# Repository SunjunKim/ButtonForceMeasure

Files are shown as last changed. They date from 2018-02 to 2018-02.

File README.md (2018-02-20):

# Button pressing force measurement device
# Last update: Feb 19, 2018
# Author: Sunjun Kim (kuaa.net@gmail.com)

Works with FSS 1500 sensor & 626 Bearing

# Parts needed
* M4 x (12--25 mm) * 3 ea (+ 3 M4 nuts)
* M6 x (15--25 mm) Flat head * 2ea
* M6 Tap (for making thread on DivingBoard part)
* 3D printed parts (See https://cad.onshape.com/documents/8884241d92b3924385b88df5/w/f3e7b9c0423dc323fdf4269c/e/ec01502cc8bd3c084f737220 for the latest version)

# Assembly
 - TBA

# Firmware
 - Upload FSS1500 to an Arduino ATMega328p (e.g., UNO) or ATMega32U4 (e.g., Leonardo) based board.
 - Serial baud rate: 115200
 - You can check the serial values from Arduino Serial monitor
 - You can log the values through the logSerial.sh bash script
  USAGE: ./logSerial.sh [PORT] [BAUD] [OUTPUT FILE]
  e.g., ./logSerial.sh /dev/tty.usbmodem1421 115200 log.csv

# Visualizer
 - Coded in Processing (tested with ver. 3.3.6, Check http://processing.org/)
 - It connects to the last serial port listed in the system (works with the most setup)
 - It first find the idle value (counting stabilized signal within <2 deviation)
 - After detecting a button press (other than idle value), it visualizes it with a graph (with some lead time before and after the button press).

 # Accelerometer
 - Accelerometer (Spartkfun ADXL335 breakout board) added to A2(X-axis), A3(Y-axis), A4(Z-axis)
 - Cx, Cy, Cz filtering capacitors --> set to 0.01uF (=500Hz bandwidth)
 - Fingertip mount ()

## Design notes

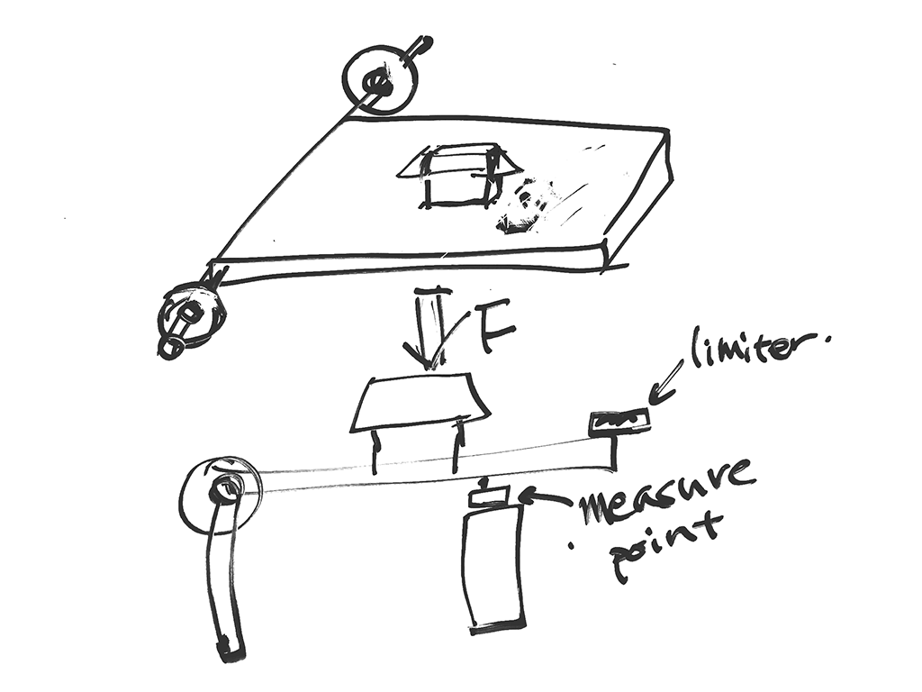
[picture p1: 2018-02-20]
Measuring_apparatus_concept.png

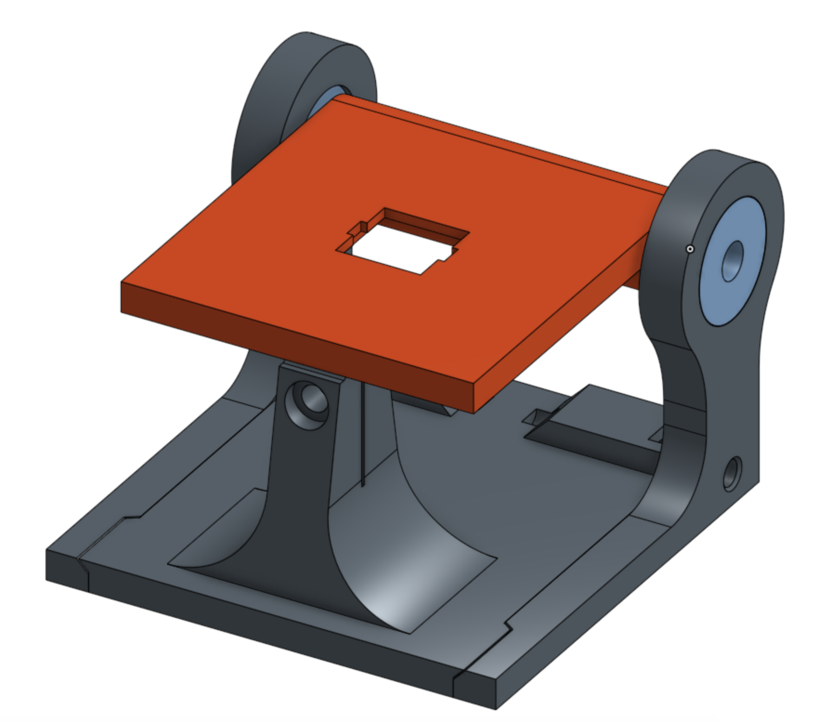
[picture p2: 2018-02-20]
Overview.png

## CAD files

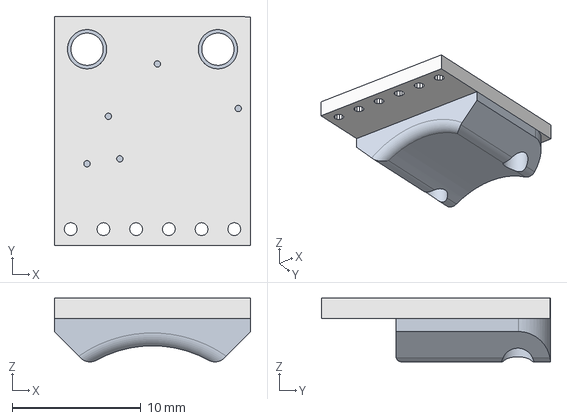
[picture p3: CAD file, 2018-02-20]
models/Fingertip_ADXL335_attachment/Fingertip_Attachment_assembly.step
15.2 x 17.8 x 4.96 mm
ADXL335_Breakout001

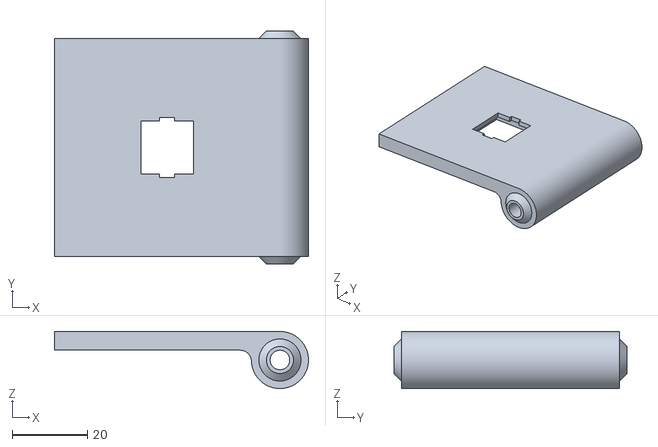
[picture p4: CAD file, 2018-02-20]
DivingBoard.stl
67.6 x 62.0 x 15.2

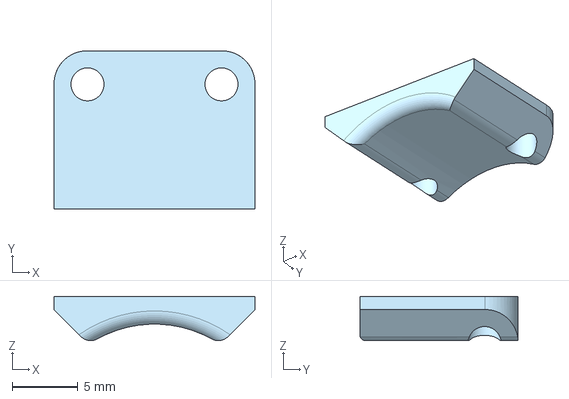
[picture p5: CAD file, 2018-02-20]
models/Fingertip_ADXL335_attachment/Fingertip_Attachment.step
15.2 x 12.0 x 3.36 mm

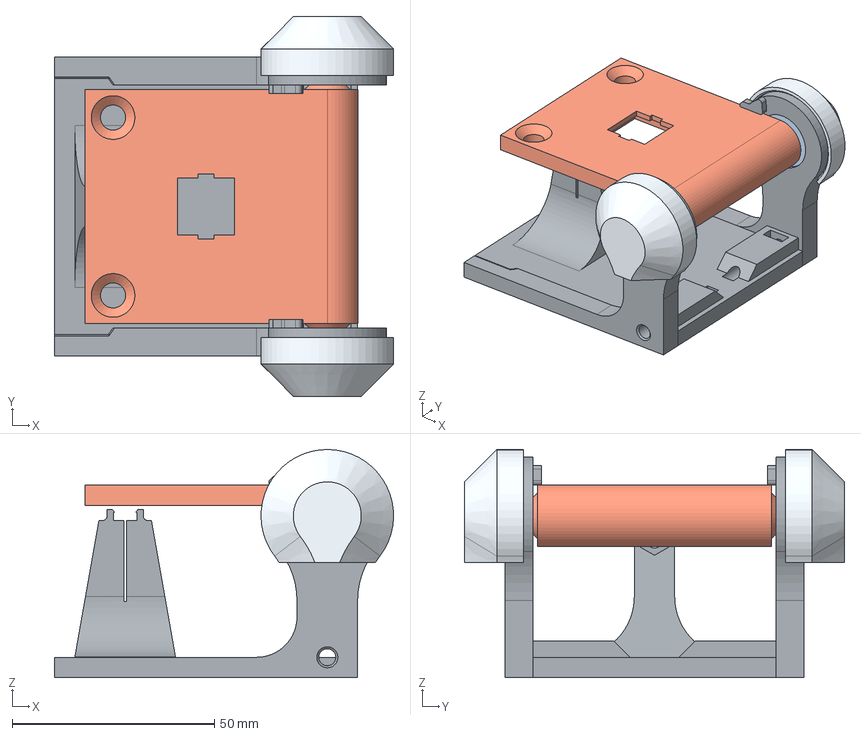
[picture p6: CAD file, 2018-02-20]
models/Mounting Base/Base.step
83.9 x 94.0 x 56.4 mm

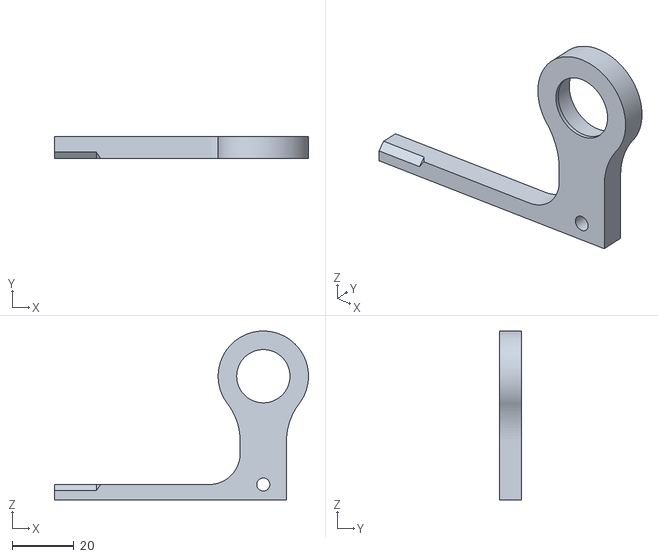
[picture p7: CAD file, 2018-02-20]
Arm_left.stl
82.1 x 7.00 x 54.6

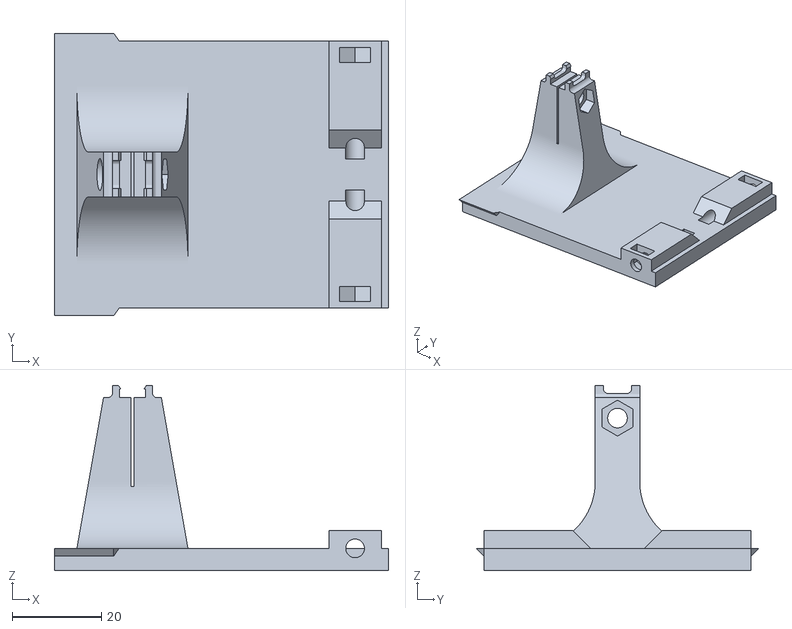
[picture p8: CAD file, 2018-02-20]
Basement.stl
75.0 x 63.4 x 41.6

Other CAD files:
models/Fingertip_ADXL335_attachment/Fingertip_Attachement.stl
Arm_right.stl

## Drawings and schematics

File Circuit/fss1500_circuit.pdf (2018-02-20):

## RefA

## RefB

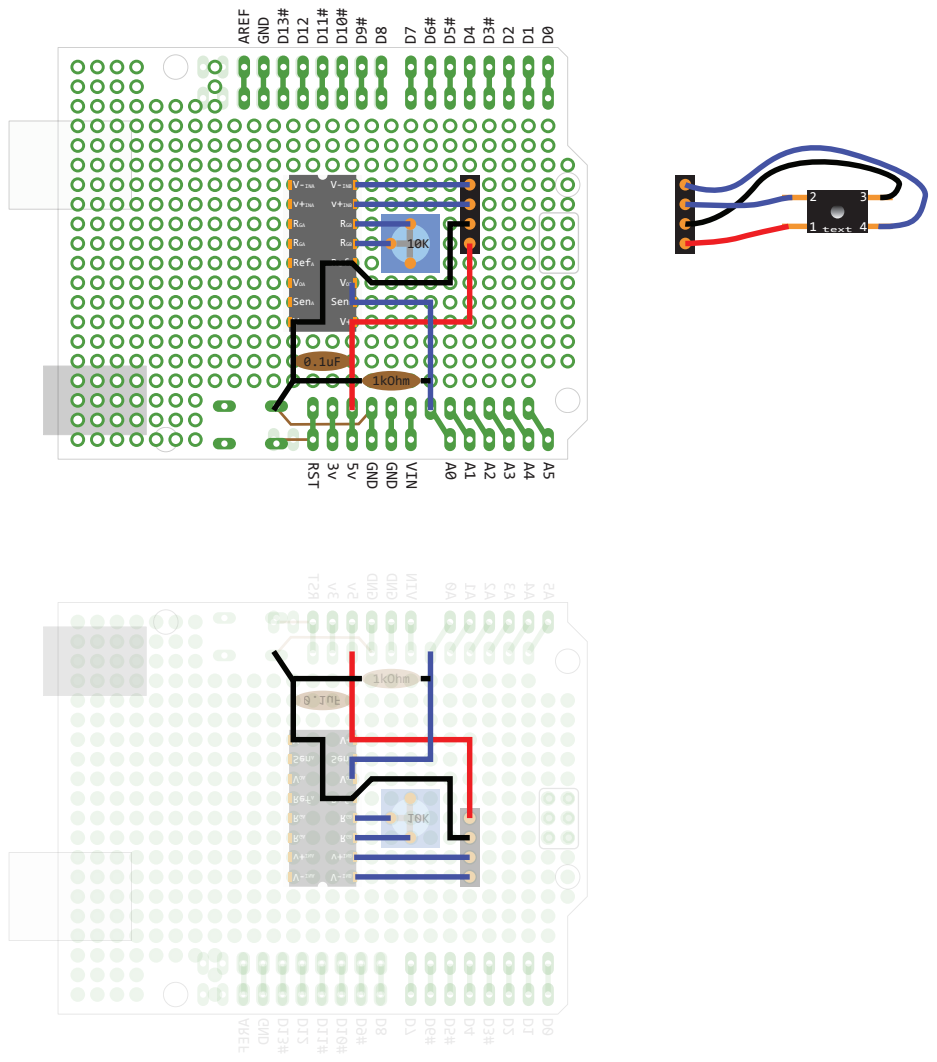
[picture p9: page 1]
AREF GND; RST; GND; VIN; AREF; RST 3v; SenA; VOA; RGA; v+INA; V-INA; SenB; VOB; RGB; v+INB; V-INB; 1kOhm; V- SenA; VOA RefA; V+ SenB; VOB RefB; 1 text

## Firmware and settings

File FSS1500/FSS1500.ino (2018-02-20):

/*
  FSS 1500 & Analog accelerometer (ADXL355) measurement
  
  Sunjun Kim

*/

int repeat = 1; // repeat counter for filtering the extreme values.

int analogInPin = A0;    // select the input pin for the potentiometer
int sensorValue = 0;  // variable to store the value coming from the sensor
int x, y, z;

int accelX = A2;
int accelY = A3;
int accelZ = A4;

unsigned long startTime;

void setup() {
  Serial.begin(115200);
  while (!Serial) ; // wait until the serial communication is estabilished.

  startTime = micros();

  pinMode(analogInPin, INPUT);
  pinMode(accelX, INPUT);
  pinMode(accelY, INPUT);
  pinMode(accelZ, INPUT);
}

void loop() {
  int val[repeat];
  int i;

  if(Serial.available() > 0)
  {
    Serial.read();
    startTime = micros();
  }

  unsigned long timestamp = micros() - startTime;

  analogRead(analogInPin); // discard one value reading, to reduce ADC switching noise. this will hold for 104us.
  sensorValue = analogRead(analogInPin);

  analogRead(accelZ);
  z = analogRead(accelZ);

  analogRead(accelY);
  y = analogRead(accelY);

  analogRead(accelX);
  x = analogRead(accelX);


  // encode values into little-endian bytes,
  // Send starting bit
  Serial.write( 0x0A );
  Serial.write( 0x41 );
  
  // Send timestamp (4 byte)
  Serial.write((timestamp)&0xff);
  Serial.write((timestamp>>8)&0xff);
  Serial.write((timestamp>>16)&0xff);
  Serial.write((timestamp>>24)&0xff);
  
  // Send values (2 bytes each)
  Serial.write( sensorValue & 0xff );
  Serial.write( (sensorValue >> 8) & 0xff );
  
  Serial.write( x & 0xff );
  Serial.write( (x >> 8) & 0xff );

  Serial.write( y & 0xff );
  Serial.write( (y >> 8) & 0xff );

  Serial.write( z & 0xff );
  Serial.write( (z >> 8) & 0xff );
}

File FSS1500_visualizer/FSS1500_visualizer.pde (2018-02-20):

import processing.serial.*;

Serial buttonPort;
int lf = 10; // linefeed char

int[] valueArray = new int[10000];
int[] displayArray = null;
int displayDuration = 0;

int numValues = 0;

int idleValue = 0;
int stabilizationCount = 50;  // number of values needed for stabilization
int stabilizationLimt = 2;

int numMarginalData = 10;
int timeKeeper = 0;

float FPMS = 0;

void setup()
{
  size(1000, 500);
  String portName =  Serial.list()[Serial.list().length - 1];
  println(portName);
  buttonPort = new Serial(this, portName, 115200);
  buttonPort.clear();
  
  background(0);
}

void draw()
{
  while (buttonPort.available() > 0) 
  {
    String str = buttonPort.readStringUntil(lf);
    if (str != null)
    {
      try
      {
        int val = Integer.parseInt(trim(str));
        if (feedValue(val))
        {
          background(0);
          translate(50, 25);
          drawChart(900, 450, displayArray, FPMS);
        }
      } 
      catch(NumberFormatException e) {
      }
    }
  }
}

boolean feedValue(int v)
{ 
  if(numValues > 9999)
  {
    numValues = 0;
    idleValue = 0;
  }
  
  if (idleValue == 0)    // idle value not detected. Do idle value detection.
  {
    valueArray[numValues++] = v;
    if (numValues >= stabilizationCount) // if collected enough values...
    {
      // calculate variance
      boolean stabilized = true;
      double mean = valueArray[0];
      for (int i=1; i<stabilizationCount; i++)
      {
        mean += valueArray[i];
        if (abs(valueArray[i] - valueArray[0]) > stabilizationLimt) // if any value deviates overs the limit; stabilization is failed. 
        {
          stabilized = false;
        }
        numValues = 0;
      }

      if (stabilized)
      {
        idleValue = (int)(mean/stabilizationCount);
        println("Stabilized: "+idleValue);
      }
    }
    return false;
  } 

  // Collecting a data  
  valueArray[numValues++] = v;
  

  // check the last subsegment of the data
  boolean pressed = false;  
  if (numValues >= numMarginalData)
  {
    for (int i=numValues - numMarginalData; i<numValues; i++)
    {
      if (abs(valueArray[i] - idleValue) > stabilizationLimt)
      {
        pressed = true;
      }
    }
  }

  if (!pressed && numValues == numMarginalData)
  {
    // shift the window. (button not pressed)
    for (int i=1; i<numMarginalData; i++)
    {
      valueArray[i-1] = valueArray[i];
    }
    numValues--;
    timeKeeper = millis();
  } else if (!pressed && numValues > numMarginalData*3)
  {
    displayDuration = millis() - timeKeeper;

    displayArray = new int[numValues];
    for (int i=0; i<numValues; i++)
    {
      displayArray[i] = valueArray[i];
    }
    // frame per millisecond
    FPMS = (float)(numValues - numMarginalData) / displayDuration;
    println("detected a button press, collected "+numValues+" datapoints in "+ displayDuration +" ms");
    
    numValues = numMarginalData-1;
    return true;
  }

  return false;
}


void drawChart(int w, int h, int[] values, float fpms)
{
  int maxVal = 0;
  int nVal = values.length;
  // find the maximum value
  for (int i=0; i<nVal; i++)
  {
    maxVal = max(maxVal, values[i]);
  }

  // fine the nearest value rounded by 20
  int graphBound = max(300, (maxVal / 20 + 1) * 20);
  // fine the nearest tick value 
  float tick = 20 * fpms; // 50 ms in frame number
  int timeBound = (int)((int)(nVal/tick + 1) * tick) + 10;
  
  float hRatio = (float)h / graphBound;
  float wRatio = ((float)w-50) / timeBound;
 
  // draw lines
  textSize(12);
  strokeWeight(1);

  // draw Horizontal lines
  for (int i=0; i<=graphBound; i+=20)
  {
    if (i % 50 == 0)
    {
      fill(255);
      noStroke();
      text(""+i, 0, h - i * hRatio - 2);

      noFill();
      stroke(0xAA);
    } else
      stroke(0x77);

    line(0, h - i * hRatio, w, h - i * hRatio);
  }  
  
  float startFrame = numMarginalData-2;
  
  // draw vertical lines
  for(float i=startFrame;i<timeBound-numMarginalData;i+=tick)
  {
    fill(255);
    noStroke();
    text((int)((i-startFrame)/fpms)+" ms", 25 + i*wRatio + 5, h - 5);

    noFill();
    stroke(0x77);
    line(25 + i*wRatio , 0, 25 + i*wRatio, h);
  }

  for (int i=1; i<nVal-1; i++)
  {
    int p1 = values[i];
    int p2 = values[i+1];

    noFill();
    strokeWeight(2);
    stroke(0xFF, 0xFF, 0x00);

    line(25 + i*wRatio, h - p1*hRatio, 25 + (i+1)*wRatio, h - p2*hRatio);
  }
}

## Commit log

2018-02-20 3D Models added, Accelerometer added
    [Base.step, Fingertip_Attachement.stl, Fingertip_Attachment.step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]
2018-02-20 protocol changed (little-endian)
    [log.csv]
